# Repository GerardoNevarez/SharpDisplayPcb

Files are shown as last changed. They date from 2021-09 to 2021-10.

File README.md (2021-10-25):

# SharpDisplayPcb

Replacement PCB for the Adafruit SHARP Memory Display Breakout (3502). Only for 3.3V.

Documentation - WIP

BOM ( Bill Of Materials )
- PCB 😄

| Ref | Qty | Value  | Description                       | Package | Manufacturer_Part | Mouser_Part          | 
------------|----------|--------|-----------------------------------|---------|-------------------|----------------------|
| FB1, FB2  |    2     |   FB   |  Ferrite Beads 0805               | 0805    | 2508051217Z3      | 623-2508051217Z3     |
| C1        |    1     |  10uF  | Ceramic Capacitors 10uF+/-10% 16V | 0805    |  CL21A106KOQNNNG  |  187-CL21A106KOQNNNG |
| C2        |    1     | 0.1uF  | Ceramic Capacitors 100nF+/-10% 50V  | 0805    |  CL21B104KBCNNNC   |  187-CL21B104KBCNNNC  |
| C3, C4    |    2     |  1uF   | Ceramic Capacitors 1uF+/-10% 16V  | 0805    |  CL21B105KOFNNNF  |  187-CL21B105KOFNNNF |
| R1        |    1     |  5.1K   | Thick Film Resistors - SMD 5.1 kOhms 125 mW 1%   | 0805    |  RC0805FR-075K1L   |  603-RC0805FR-075K1L  |
| J2        |    1     |  ZIF   | FFC & FPC Connectors 0.5mmpitch 10Ckt | 10 pin FPC    |  505278-1033   |  538-505278-1033  |

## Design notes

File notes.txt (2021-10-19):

ZIF connector

Adafruit used: Molex 52892-1095
obsoleted, Mouser suggested: Molex 52892-1033
footprint compatible!  but Molex now says: New Business Not Supported
and recommends: Molex 505278-1033, which has a different footprint
and is a bit cheaper, enough to cover the cost of PCBs at JLC

Oh...  and Sharp recommended Molex: 51441-1093... which is also obsolete.
replacement recommended is also 505278-1033

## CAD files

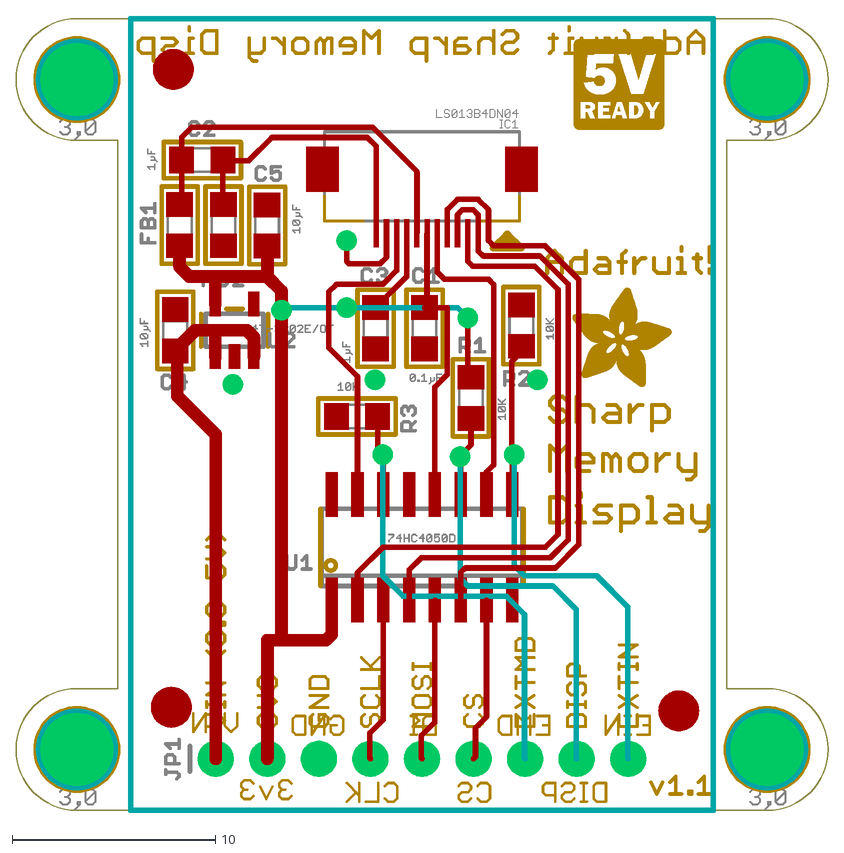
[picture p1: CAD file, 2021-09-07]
Adafruit_references/Adafruit_SharpMemoryDisplay.dxf
40.0 x 39.3

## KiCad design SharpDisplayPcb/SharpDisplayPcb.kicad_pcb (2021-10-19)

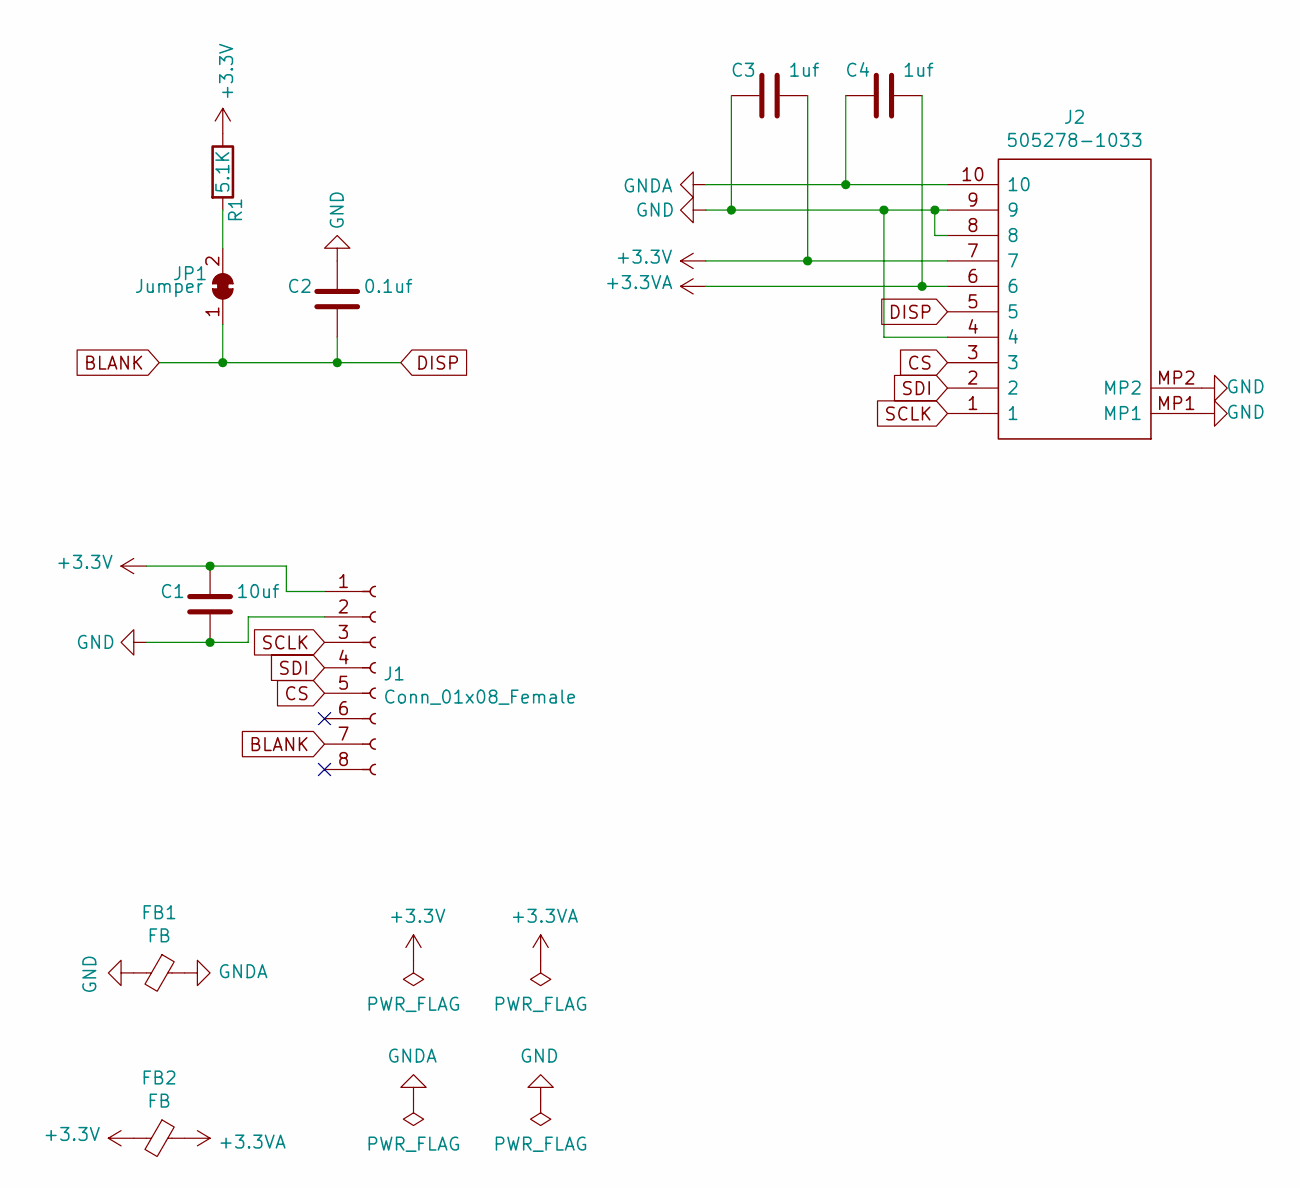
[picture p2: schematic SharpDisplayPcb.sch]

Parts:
C1: 10uf; C_0805_2012Metric_Pad1.18x1.45mm_HandSolder
C2: 0.1uf; C_0805_2012Metric_Pad1.18x1.45mm_HandSolder
C3, C4: 1uf; C_0805_2012Metric_Pad1.18x1.45mm_HandSolder
FB1, FB2: FB; L_0805_2012Metric_Pad1.15x1.40mm_HandSolder
J1: Conn_01x08_Female; PinHeader_1x08_P2.54mm_Vertical
J2: 505278-1033; 5052781033; Mouser Part Number 538-505278-1033
JP1: Jumper; SolderJumper-2_P1.3mm_Bridged_Pad1.0x1.5mm
R1: 5.1K; R_0805_2012Metric_Pad1.20x1.40mm_HandSolder

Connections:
+3.3VA: C4.2, FB2.1, J2.6
+3V3: C1.1, C3.2, FB2.2, J1.1, J2.7, R1.1
BLANK: C2.2, J1.7, J2.5, JP1.1 (A)
CS: J1.5, J2.3
GND: C1.2, C2.1, C3.1, FB1.2, J1.2, J2.4, J2.8, J2.9, J2.MP1, J2.MP2
GNDA: C4.1, FB1.1, J2.10
unnamed: JP1.2 (B), R1.2
SCLK: J1.3, J2.1
SDI: J1.4, J2.2

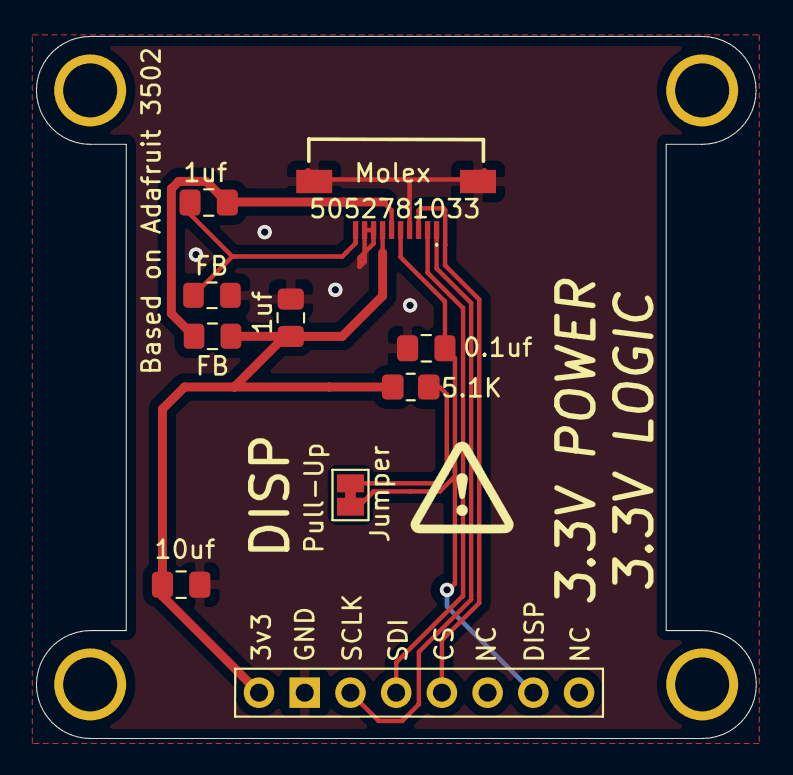
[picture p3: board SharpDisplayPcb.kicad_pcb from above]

Board: 2 copper layers, 40.0 x 39.0 mm, 14 parts (0 on the bottom side), 9 nets.

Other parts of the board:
M3, M3#2, M3#3, M3#4: MH3; MountingHole_3mm_Pad

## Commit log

2021-09-07 Add Adafruit files, for reference
    [Adafruit_SharpMemoryDisplay.dxf]
2021-09-07 PCB border, start schematic
    [SharpDisplayPcb.kicad_pcb, SharpDisplayPcb.sch]
2021-09-08 Completed schematics, initial PCB layout
    [Adafruit_SharpMemoryDisplay.dxf, SharpDisplayPcb.kicad_pcb, SharpDisplayPcb.sch]
2021-10-19 Add DISP jumper, to disable pull-up resistor
    [SharpDisplayPcb-B_Cu.gbr, SharpDisplayPcb-B_Mask.gbr, SharpDisplayPcb-B_Paste.gbr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]
2021-10-19 Better routing for 3v3 bypass capacitor
    [SharpDisplayPcb-B_Cu.gbr, SharpDisplayPcb-B_Mask.gbr, SharpDisplayPcb-B_Paste.gbr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]
2021-10-19 Added notes with ZIF connector drama
2021-10-19 Remove pull-down resistors, adjust layout
    [SharpDisplayPcb-B_Cu.gbr, SharpDisplayPcb-B_Mask.gbr, SharpDisplayPcb-B_Paste.gbr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]
2021-10-19 Replace ZIF part, move components out of ZIF footprint
    [SharpDisplayPcb-B_Cu.gbr, SharpDisplayPcb-B_Mask.gbr, SharpDisplayPcb-B_Paste.gbr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]
